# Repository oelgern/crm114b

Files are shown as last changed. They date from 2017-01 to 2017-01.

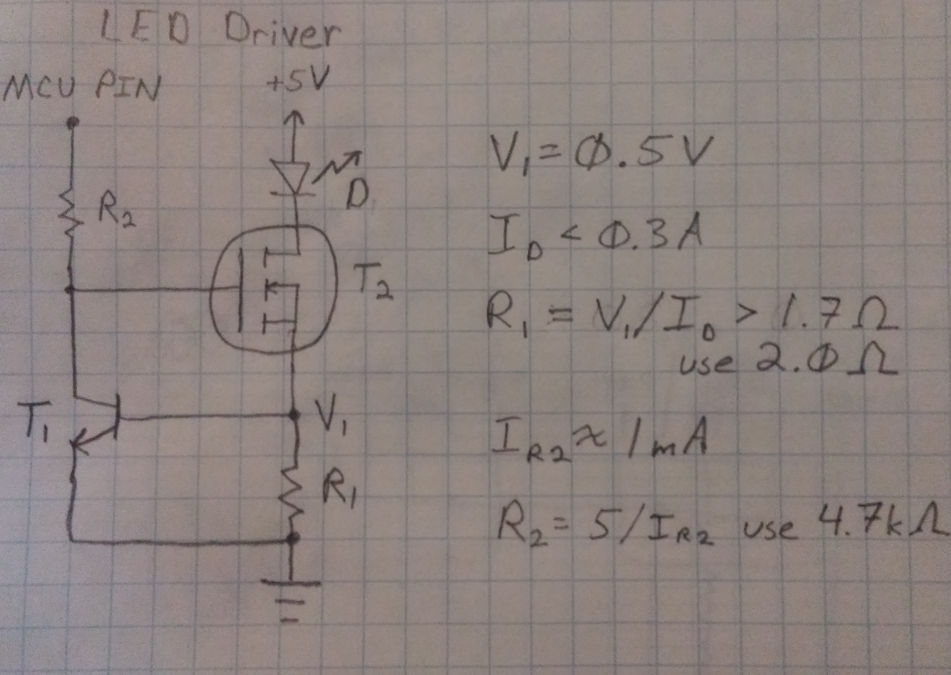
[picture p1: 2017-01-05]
circuit_design/driver.jpg

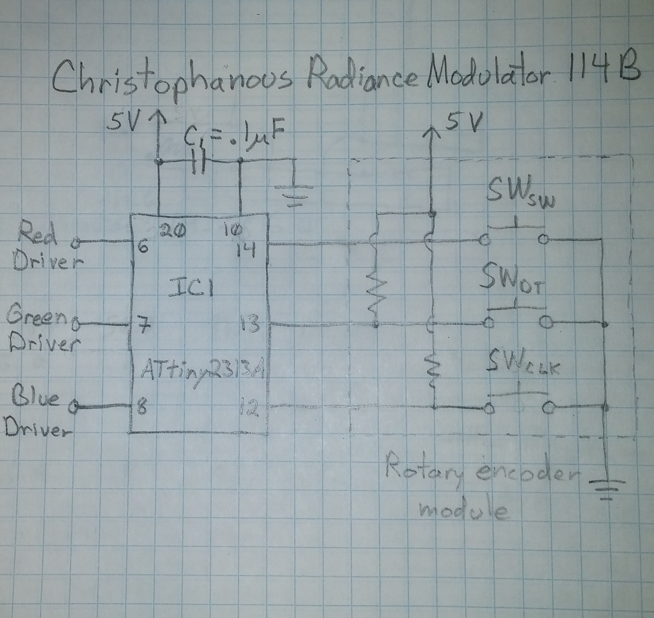
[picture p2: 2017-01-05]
circuit_design/circuit.jpg

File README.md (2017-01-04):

# crm114b
Christophanous Radiance Modulator, Model 114B (CRM-114B)

Precision manual PWM is used to create visually appealing colored light patterns. The original application was for a Christmas tree star topper in the form of an Ikea STRALA fiber optic light fixture (discontinued, see https://www.amazon.com/dp/B00B29CVR8?tag=mydegun-20) retrofitted with an ATtiny2313A microcontroller controlling a 3-watt RGB LED. Control of the pattern mode, speed, and intensity is provided with a rotary encoder.

This original application was an entry to the Hackaday 1kB Challenge: https://hackaday.io/project/19252-christophanous-radiance-modulator-model-114b

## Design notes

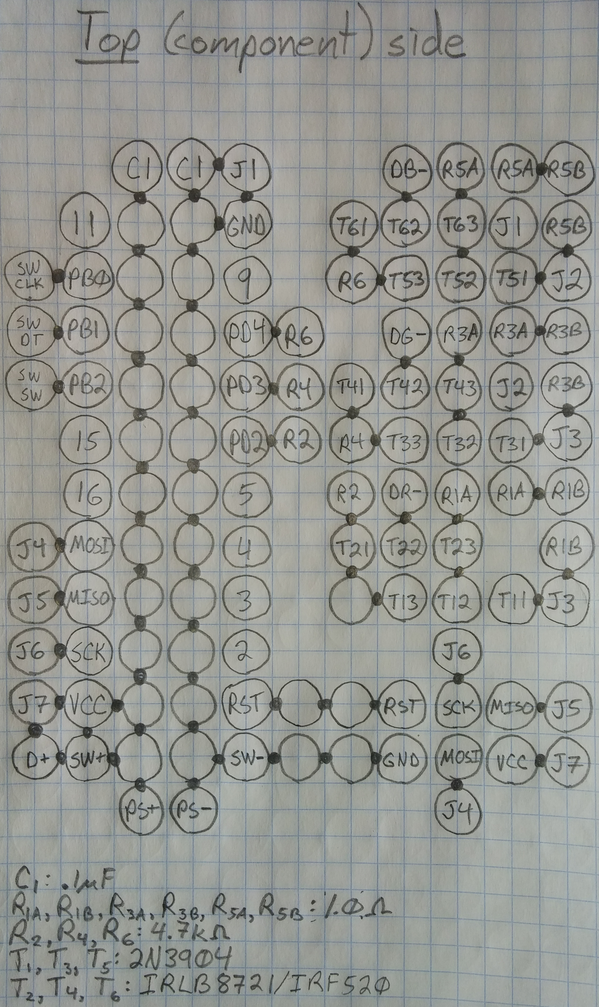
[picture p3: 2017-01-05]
circuit_design/perfboard_layout.jpg

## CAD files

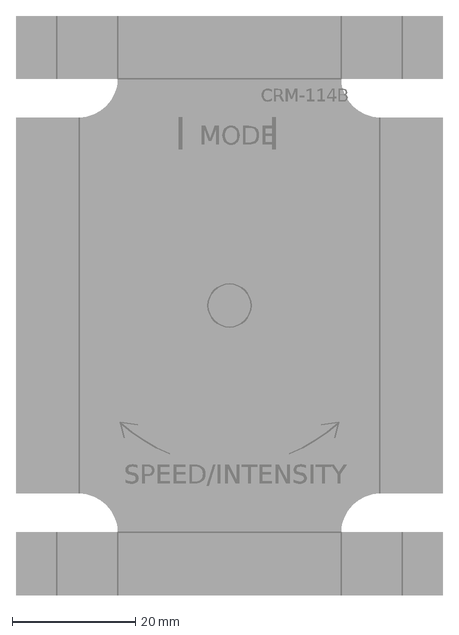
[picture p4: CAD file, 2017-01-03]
panel/crm114b_underlay.dxf
CRM-114B
MODE
SPEED/INTENSITY
l

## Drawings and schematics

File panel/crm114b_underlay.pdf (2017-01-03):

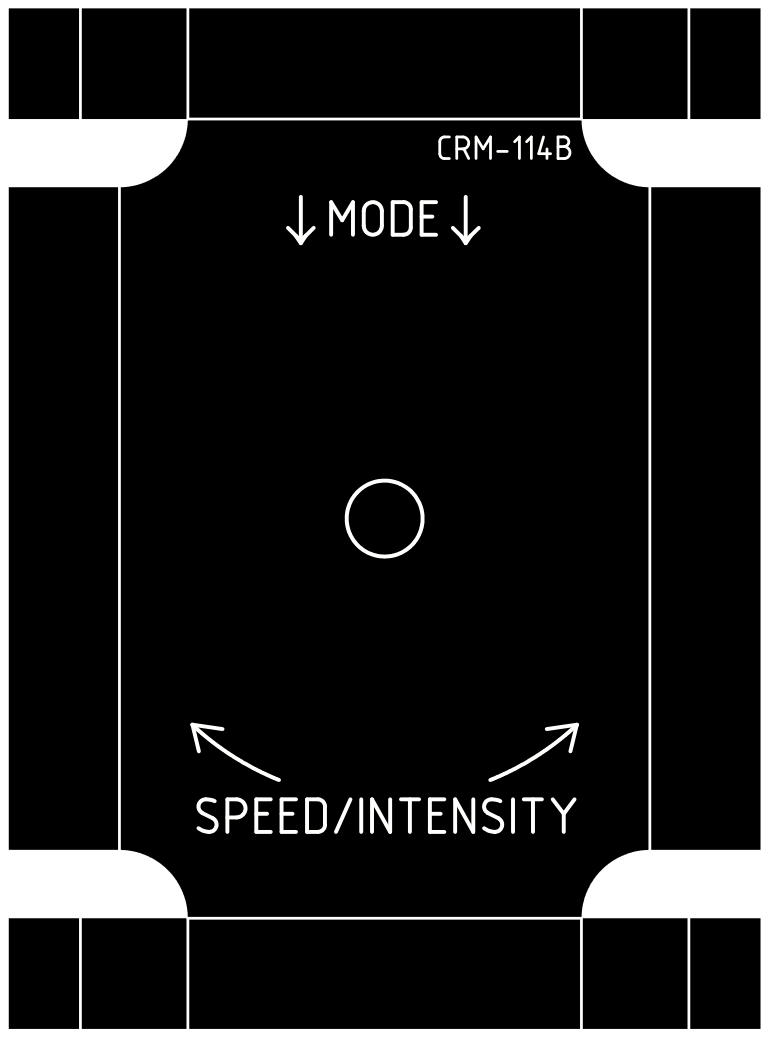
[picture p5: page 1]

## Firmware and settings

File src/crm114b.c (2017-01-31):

// Christophanous Radiance Modulator, model 114B (CRM 114B)
//  https://github.com/oelgern/christophanousRadianceModulator114B
//
// Description:
//
//  Precision manual PWM is used to create visually appealing colored light
//   patterns. The original application was for a Christmas tree star topper in
//   the form of an Ikea STRALA fiber optic light fixture (discontinued, see
//   https://www.amazon.com/dp/B00B29CVR8?tag=mydegun-20) retrofitted with an
//   ATtiny2313A microcontroller controlling a 3-watt RGB LED. Control of the
//   pattern mode, speed, and intensity is provided with a rotary encoder.
//
//  The hardware-based PWM available with the selected microcontroller did not
//   not have enough channels with the desired resolution, so manual PWM was
//   used instead. Additionally, standard PWM algorithms don't account for the
//   non-linearity of humans' perception of light intensity. As an example, the
//   perceived difference between a 1% and 2% duty cycle is much greater than
//   that between 98% and 99%. Therefore, the algorithm used with this project
//   changes the intensity exponentially to create a uniformly smooth transition
//   throughout its intensity range.
//
//  This project was submitted as an entry to hackaday's 1kB Challenge contest
//   (see https://hackaday.io/contest/18215-the-1kb-challenge) which challenges
//   contestants to submit projects that are limited in their usage of program
//   memory to 1kB. As such, many things were done to reduce the required
//   program space. Some of the more obvious ones include:
//    * Using compiler program space optimization option.
//    * Using the smallest data type possible.
//    * Declaring functions to be static.
//    * Using else-ifs instead of a case statement.
//    * Omitting conditionals around certain code if its unnecessary execution
//       doesn't have an adverse effect.
//    * Omitting conditionals around certain code if the logic dictates it is
//       the only possibility.
//    * Using unsigned variables where possible.
//    * Using do-while loops where possible.
//    * Using descending loop counters and pre-decrementing where possible.
//    * Inverting a variable at calculation time where its inversion would
//       subsequently be used for multiple comparisons.
//
//  Others aren't as obvious:
//    * Connecting similar hardware to the same port (inputs on one port,
//       outputs on another) and to consecutive pins of the microcontroller.
//    * Using unions to allow single byte access of 16-bit variables when
//       possible and beneficial.
//    * Using a larger data type where used by a macro--see note on
//       prand_address.
//    * Eliminating volatile modifier for some variables, where experience would
//       suggest it is needed.
//    * Conspicuously rearranging code into a non-intuitive order that the
//       compiler optimizer can take advantage of.
//    * Implementing a number of modes that are equal to a power of two.
//    * Designing software so that all needed multiply and division operations
//       are of powers of two, which use bit shifts.
//    * Using runtime variable limitation logic in lieu of variable
//       initialization performed at declaration time.
//    * Placing code that references the same variables close to each other to
//       take advantage of compiler optimizer's abilities.
//    * Reading data from the program space to use as psuedo-random values.
//
//  See the comments embedded in the code for more details.
//
// Connections:
//
//   Outputs       +-\/-+        Inputs
//           PA2  1|    |20  VCC
//           PD0  2|    |19  PB7
//           PD1  3|    |18  PB6
//           PA1  4|    |17  PB5
//           PA0  5|    |16  PB4
//   Red LED PD2  6|    |15  PB3
// Green LED PD3  7|    |14  PB2 Switch button
//  Blue LED PD4  8|    |13  PB1 Switch DT
//           PD5  9|    |12  PB0 Switch CLK
//           GND 10|    |11  PD6
//                 +----+
//
// See: https://github.com/oelgern/christophanousRadianceModulator114B/wiki
//  for additional information.
//
// Code and all project-related design files authored by and released to public
//  domain (whatever that means) by Nathan Oelger, 2017-01-02.
//
// Built with avr-gcc 4.9.2 using -Os
//  1000 bytes program space used
//  0 bytes EEPROM used
//
// Possible improvements:
//  Additional/different pattern modes
//  Optimizations:
//   Redefine the interrupt vector table. This should save 20 bytes of program
//    space.
//   Reconnect/redefine LED ports to PD0..2. This saves 8 bytes of program
//    space by reducing the bit shifts.
//   Add pull-up resistor for switch button so code to turn the internal pull-up
//    on won't be necessary. This saves 4 bytes of program space.

// Includes
#include <avr/interrupt.h>
#include <avr/pgmspace.h>

// Approximate clock speed after manipulation of CLKPR and OSCCAL
#define F_CPU 13000000UL

// Definitions for input hardware
#define SWITCH_DATA_DIRECTION DDRB
#define SWITCH_PORT PORTB
#define SWITCH_STATES PINB
#define SWITCH_CLK PB0
#define SWITCH_DT PB1
#define SWITCH_BUTTON PB2
#define SWITCH_MASK (1 << SWITCH_CLK) | (1 << SWITCH_DT) | (1 << SWITCH_BUTTON)

// Definitions for output hardware
#define LED_DATA_DIRECTION DDRD
#define LED_PORT PORTD
#define LED_RED PD2
#define LED_GREEN PD3
#define LED_BLUE PD4
#define LED_MASK (1 << LED_RED) | (1 << LED_GREEN) | (1 << LED_BLUE)
#define NUM_LEDS 3

// Function declarations
//  These are only called once. Declaring these static tells the compiler to
//  optimize them as inline. This saves an additional 52 bytes of program space.
static void init_devices(void);
static void timer1_init(void);
static void read_switches(void);
static void create_pattern(void);
static void scale_intensities(void);
static void calculate_LED_times(void);

// Enumeration list of pattern modes
//  Assigned values so as to leave less to chance.
enum Mode
{
  RANDOM_APPROACH = 0,
  RANDOM_FLIP     = 1,
  PRIMARY_GROW    = 2,
  SECONDARY_FLIP  = 3,
  MANUAL_RED      = 4,
  MANUAL_GREEN    = 5,
  MANUAL_BLUE     = 6,
  TWINKLE         = 7,
  NUM_MODES       = 8 // This needs to be the last mode.
};

// The currently selected pattern mode
static uint8_t current_mode;

// Used to keep track of clockwise/counter-clockwise movement of the rotary
//  encoder.
static int8_t knob_adjustment;

// Linear levels of brightness of each of the three colors.
uint8_t levels[NUM_LEDS];

// Exponentially scaled intensity levels of brightness of each of the three
//  colors.
// Union used to allow access to high/low individual bytes which can save
//  program space.
union
{
   uint8_t  bytes[NUM_LEDS * 2];
   uint16_t value[NUM_LEDS];
} intensities;

// States of the light channels for each of the four minor frames of a major
//  frame. See calculate_LED_times() for more information.
uint8_t on_masks[4]; // Used at the beginning of major and minor frames

// States of the light channels after partial periods--used at conclusion of
//  partial periods
volatile uint8_t off_masks[3];

// Times of ends of partial periods
volatile uint16_t off_timers[NUM_LEDS];

// Buffered state of light channels for beggining of the next minor frame.
volatile uint8_t turn_on_mask;

// Buffered state of light channels for end of the next partial period.
volatile uint8_t turn_off_mask;

// The main routine. Everything starts here.
int main(void)
{

  // Initialize all microcontroller hardware.
  init_devices();

  // This will repeat until power is lost.
  for( ; ; )
  {

  // Nothing to do here. Everything called from interrupts.
  }
}

// This function initializes all hardware.
void init_devices(void)
{

  // Disable errant interrupts until set up.
  //cli(); // Bit initialized to disabled, so this isn't needed.

  // Disable the watchdog timer. This isn't needed as watchdog isn't used.
  // Reset the watchdog timer.
  // asm volatile("wdr");

  // Clear WDRF in MCUSR.
  //MCUSR &= ~(1<<WDRF); // Register initialized to zero, so this isn't needed.

  // Write logical one to WDCE and WDE.
  //WDTCSR |= (1<<WDCE) | (1<<WDE); // Not needed.

  // Turn off WDT.
  //WDTCSR = 0x00; // Register initialized to zero, so this isn't needed.

  // Clear the divide-by-eight clock bit so microcontroller runs at full speed.
  //  Per the datasheet, this requires a special procedure.
  //  1. Write CLKPCE high and all other bits low.
  CLKPR = 1 << CLKPCE;

  //  2. Write CLKPCE low and all other bits as desired.
  //  Note: uint8_t typecast here eliminates warning about truncated unsigned
  //   type due to the default behavior of arithmetic being performed as signed
  //   16-bit.
  CLKPR = (uint8_t)(~(1 << CLKPCE)) &

          // Without the following 3 additional (seemingly unecessary) lines, an
          //  additional 2 bytes of program space are used.
          (~(1 << 6)) &
          (~(1 << 5)) &
          (~(1 << 4)) &

          // CLKPS3..0 corresponds to a CLK/1 (no prescaler).
          (~(1 << CLKPS0)) &
          (~(1 << CLKPS1)) &
          (~(1 << CLKPS2)) &
          (~(1 << CLKPS3));

  // Squeeze extra speed out of internal oscillator. According to the datasheet
  //  this, along with the CLK/1 prescaler, should set the internal oscillator
  //  speed to about 13MHz.
  OSCCAL = (1 << CAL0) |
           (1 << CAL1) |
           (1 << CAL2) |
           (1 << CAL3) |
           (1 << CAL4) |
           (1 << CAL5) |
           (1 << CAL6);

  // Configure switches as inputs.
  //SWITCH_DATA_DIRECTION &= ~SWITCH_MASK; // Register initialized to zero, so
                                           //  this isn't needed.

  // Enable pull-up resistor for switch pushbutton.
  SWITCH_PORT = (1 << SWITCH_BUTTON);

  // Configure LED color channels as outputs.
  LED_DATA_DIRECTION = LED_MASK;

  // Turn off color channels.
  //LED_PORT &= (~(1 << LED_RED)) &
              //(~(1 << LED_GREEN)) &
              //(~(1 << LED_BLUE));  // Register initialized to zero, so this
                                     //  isn't needed.

  // Initialize timer 1--the 16-bit timer.
  timer1_init();

  sei(); // Enable interrupts.
  // All peripherals are now initialized.
}

// Initialize 16-bit timer1.
void timer1_init(void)
{

  // Set CS12:0 to 0 to stop the timer while we set it up.
  //TCCR1B &= ~(1<<CS10); // Initialized to zero, so this isn't needed.
  //TCCR1B &= ~(1<<CS11); // Initialized to zero, so this isn't needed.
  //TCCR1B &= ~(1<<CS12); // Initialized to zero, so this isn't needed.

  // Reset the timer count to 0.
  //TCNT1 = 0; // Initialized to zero, so this isn't needed.

  // Set COM1A1:0 and COM1B2:0 to 0 disabling the compare output pin modes.
  //TCCR1A &= ~(1<<COM1A1); // Initialized to zero, so this isn't needed.
  //TCCR1A &= ~(1<<COM1A0); // Initialized to zero, so this isn't needed.
  //TCCR1A &= ~(1<<COM1B1); // Initialized to zero, so this isn't needed.
  //TCCR1A &= ~(1<<COM1B0); // Initialized to zero, so this isn't needed.

  // Set WGM13:0 to 0b0000 enabling Normal mode.
  //TCCR1A &= ~(1<<WGM10); // Initialized to zero, so this isn't needed.
  //TCCR1A &= ~(1<<WGM11); // Initialized to zero, so this isn't needed.
  //TCCR1B &= ~(1<<WGM12); // Initialized to zero, so this isn't needed.
  //TCCR1B &= ~(1<<WGM13); // Initialized to zero, so this isn't needed.

  // Disable input capture options.
  //TCCR1B &= ~(1<<ICNC1); // Initialized to zero, so this isn't needed.
  //TCCR1B &= ~(1<<ICES1); // Initialized to zero, so this isn't needed.

  // Set CS12:0 to 0b001 to start the timer incrementing and to enable the
  //  timer's clock source as the system clock with no prescaler (that is, a
  //  scale divider value of "1").
  TCCR1B = (1<<CS10);
  //TCCR1B &= ~(1<<CS11); // Initialized to zero, so this isn't needed.
  //TCCR1B &= ~(1<<CS12); // Initialized to zero, so this isn't needed.

  // Enable the TIMER1 overflow interrupt.
  TIMSK /*|*/= (1<<TOIE1)/*;*/

  // Enable the timer1's output compare A match interrupt.
  /*TIMSK */|/*=*/ (1 << OCIE1A)/*;*/

  // Enable the timer1's output compare B match interrupt.
  /*TIMSK */|/*=*/ (1 << OCIE1B);

  // Disable the TIMER1 input capture interrupt.
  //TIMSK &= ~(1<<ICIE1); // Initialized to zero, so this isn't needed.
}

// This interrupt routine will automagically be called everytime TIMER1 has
//  overflowed.  See timer1 stuff in init_devices() to see how the timer was
//  setup.
//  13000000 CPU cycle   timer cycle        overflow         200 overflows
//  ------------------ * ----------- * ------------------ ~= -------------
//        second         1 CPU cycle   65536 timer cycles       second
//  or an overflow about every 5.0 milliseconds.
// The contents of this method would typically be minimalistic (set a flag for
//  main method to check). Unfortunately, putting the logic contained below into
//  the main method had significant undesired effects. After spending some time
//  trying to figure it out, I gave up and put it inside this ISR. It probably
//  works because this disallows other interrupts from altering the logic flow
//  contained herein.
ISR(TIMER1_OVF_vect)
{

  // Read the rotary encoder position changes and button depressions, and
  //  change mode (based on button depressions).
  read_switches();

  // Calculate the light pattern based on mode, time, and other variables.
  create_pattern();

  // Exponentially scale the light intensities, accounting for the non-linearity
  //  of humans' perception of light intensity.
  scale_intensities();

  // Calculate when, and how long each of the color channels will be lit.
  calculate_LED_times();
}

// Read the rotary encoder position changes and button depressions, and change
//  mode (based on button depressions).
void read_switches(void)
{

  // The state of the switches remembered from the previous frame.
  static uint8_t last_switches;

  // Copy the SWITCH_STATES to a temporary variable.  Since SWITCH_STATES is
  //  treated as volatile, this ends up saving 4 bytes of program space
  //  (compiler would copy SWITCH_STATES every time it is called out in the
  //  following code).
  uint8_t inverted_switches = ~SWITCH_STATES;

  // Rotary encoder signals
  // CLK DT Knob position
  // 1   1
  // 0   1  Counter-clockwise from detent
  // 0   0  <- Detent position
  // 1   0  Clockwise from detent
  // 1   1

  // Rotary encoder just got finished transitioning.
  // Look at just the encoder's clock signal.
  if ((1 << SWITCH_CLK) &

      // This is the current state of the switches, inverted.
      inverted_switches &

      // Compare to state of switches during previous frame.
      last_switches)
  {

    // The rotary encoder's clock signal has changed.

    // Knob was turned clockwise.
    if (last_switches & (1 << SWITCH_DT))
    {

      // Increase speed/intensity, depending on mode. Used in create_pattern().
      knob_adjustment = 1;
    }

    // Knob was turned counter-clockwise.
    else
    {

      // Decrease speed/intensity, depending on mode. Used in create_pattern().
      knob_adjustment = -1;
    }
  }

  // Examine button signal.
  // Look at just the encoder's clock signal.
  if ((1 << SWITCH_BUTTON) &

      // This is the current state of the switches, inverted.
      inverted_switches &

      // Compare to state of switches during previous frame.
      last_switches)
  {

    // Transition to the next pattern mode.
    current_mode ++;

    // Return to beginning of mode list if beyond the end of the list.
    //  The following only works if the number of modes is a power of two.
    current_mode &= (NUM_MODES - 1);

    // Initialize random color approach mode
    if (current_mode == RANDOM_APPROACH)
    {

      // Nothing needed for initialization of this mode.
    }

    // Initialize random color flip-through mode
    else if (current_mode == RANDOM_FLIP)
    {

      // Nothing needed for initialization of this mode.
    }

    // Initialize primary color grow mode.
    else if (current_mode == PRIMARY_GROW)
    {

      // Space out color levels evenly--256/3 = 85.3.
      levels[0] = 0;
      levels[1] = 85;
      levels[2] = 171;
    }

    // Initialize secondary color flip-through mode
    else if (current_mode == SECONDARY_FLIP)
    {

      // Nothing needed for initialization of this mode.
    }

    // Initialize manual red mode
    else if (current_mode == MANUAL_RED)
    {

      // Nothing needed for initialization of this mode.
    }

    // Initialize manual green mode
    else if (current_mode == MANUAL_GREEN)
    {

      // Nothing needed for initialization of this mode.
    }

    // Initialize manual blue mode
    else if (current_mode == MANUAL_BLUE)
    {

      // Nothing needed for initialization of this mode.
    }

    // Initialize twinkle mode.
    else if (current_mode == TWINKLE)
    {

      // Nothing needed for initialization of this mode.
    }
  }

  // Remember the switches states for comparison during the subsequent frame.
  last_switches = ~inverted_switches;
}

// Calculate the light pattern based on mode, time, and other variables.
void create_pattern(void)
{

  // Subsequent levels of brightness of each of the three colors used by the
  //  random color approach and random color flip-through modes.
  static uint8_t goals[NUM_LEDS];

  // Psuedo-random number generator address. Program space-efficient PRNG uses
  //  program space bytes to choose colors that appear visually to be random.
  // Oddly enough, declaring this as 16-bit (vs. 8-bit) saves 10 bytes of
  //  program space. This is due to it being used as an address and extra
  //  manipulation compiler performs for the 8-bit.
  static uint16_t prand_address;

  // Delay variable (controlled by rotary encoder's knob)
  static uint8_t delay;

  // Frame counter used in conjunction with the delay variable to control the
  //  speed of the color transitions.
  static uint8_t frame_counter;

  // Frame counter used to further slow down speed of certain color transitions.
  static uint8_t slow_counter;

  // Temporary variable used for code space savings. Stores the value of the
  //  color level that's currently being manipulated. Using this variable saves
  //  22 bytes of codespace.
  uint8_t current_level;

  // The rotary encoder was just turned clockwise.
  if (knob_adjustment == 1)
  {

    // Add a delay to the color transitions (speed them up).
    delay >>= 1;
  }

  // The rotary encoder was just turned counter-clockwise and
  else if ((knob_adjustment == -1) &&

           // the delay isn't at its highest limit.
           (delay < 64))
  {

    // Remove a delay from the color transitions (slow them down).
    delay <<= 1;
  }

  // If the delay is reduced too much.
  //  Also, this reduces program space that might otherwise be used to
  //   initialize this variable during its declaration.
  //  Additionally, having this here instead of a conditional check above saves
  //   additional program space.
  if (delay == 0)
  {

    // Set the delay to the minimum--a zero can't be bit-shifted to the left, so
    //  will always need at least a '1' in delay.
    delay = 1;
  }

  // Increment to the frame counter.
  //  Placing this here next to a conditional that references it saves program
  //   space due to compiler optimizer recognizing that it is already in a
  //   register.
  frame_counter ++;

  // Only do the following if we've waited long enough.
  if ((frame_counter & (delay - 1)) == 0)
  {

    // Increment the additional slowing counter.
    slow_counter ++;

    // Set the level values for each of the color channels
    uint8_t channel = NUM_LEDS;
    do
    {

      // Decrement color channel counter.
      channel --;
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
